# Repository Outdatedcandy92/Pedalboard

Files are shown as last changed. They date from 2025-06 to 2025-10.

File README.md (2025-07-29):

# DIY Guitar Pedals

>This project aims to create a DIY friendly and Mod-able version of  the iconic Boss DS-1 and Big Muff Pi.

Modern guitar pedals such as the DS-1 and Big Muff Pi are **super expensive**!! and the new pedals that are being produced all have SMD components which make it harder to mod and repair. I always wanted to get a DS-1 but its price tag really put me off, so I did a bit of research and found a really good circuit analysis of the DS-1 on [ElectroSmash's Website](https://www.electrosmash.com/boss-ds1-analysis) and decided to create my own [DS-1](https://github.com/Outdatedcandy92/DistortionPedal) and it was really rewarding project and the results were also very good. 
Since my DS-1 Version 1 had really good results, I decided to design an even upgraded version of it which fixes problems in version 1, In addition to that I also created a PCB for the Big Muff Pi.

https://github.com/user-attachments/assets/e87293e5-299d-45d1-807d-6a7f5c813e14

https://github.com/user-attachments/assets/bea94fd8-728a-4ede-ab68-e8244417e8f7

*DS-1 PCB*


*Big Muff PCB*


---

### DS-1









### Big Muff Pi








### 3PDT Breakout Board (Optional)





  ---
## BOM

More detailed BOM with parts lists is under the `src` folder 

### DS-1 Components
| **Reference** | **Value / Part Number** |
| --- | --- |
| C1, C3 | 47n |
| C2, C8, C9 | 0.47µF |
| C4 | 250pF |
| C5 | 68n |
| C7 | 100pF |
| C10 | 0.01µF |
| C11 | 0.022µF |
| C12 | 0.1µF |
| C13 | 0.047µF |
| C14 | 1µF |
| C15 | 47µF |
| C23 | 100µF |
| D1 | 1N4004 |
| D4, D5, D8 | D1N4148 |
| Q1, Q2, Q3 | 2SC2240 |
| R1, R22 | 1K |
| R2, R7 | 470K |
| R3, R8, R18, R21, R24, R25 | 10K |
| R4, R5, R10, R11, R23 | 100K |
| R9 | 22Ω |
| R13 | 4.7K |
| R14, R15 | 2.2K |
| R16, R17 | 6.8K |
| R19, R20 | 1M |
| R39 | 47K |
| U1 | NJM3404A (M5223AL, BA728N equiv.) |
| VR1, VR2 | 100KB |
| VR3 | 20KB |
| J1, J2 | 6.35mm Jacks |
| | |

### Big Muff Pi

| **Component Type** | **Value / Part Number** | **Designators** |
|---|---|---|
| NPN Transistors | BC239 or 2N5088, 2N5089, BC549C, SE4010, 2N5210 | Q1, Q2, Q3, Q4 |
| Silicon Diodes | 1N914 or 1N4148 | D1, D2, D3, D4 |
| Potentiometers (Lin) | 100K | Sustain, Tone, Volume |
| Resistors | 10K | R13, R19, R18, R11, R12 |
| Resistors | 100K | R20, R16, R3 |
| Resistors | 470K | R9, R17, R15 |
| Resistors | 39K | R2, R8 |
| Resistors | 150 | R21, R10 |
| Resistors | 15K | R6 |
| Resistor | 47K | R14 |
| Resistor | 100 | R22 |
| Resistor | 3.3K | R4 |
| Resistor | 1K | R23 |
| Resistor | 22K | R5 |
| Capacitors | 1µF | C1, C4, C6, C7 |
| Capacitors | 100nF | C5, C13, C3, C2 |
| Capacitors | 470pF | C10, C11, C12 |
| Capacitor | 4nF | C9 |
| Capacitor | 10nF | C8 |

#### Credits

[ElectroSmash Boss DS-1 Analysis](https://www.electrosmash.com/boss-ds1-analysis)
[ElectroSmash Big Muff Pi Analysis](https://www.electrosmash.com/big-muff-pi-analysis)

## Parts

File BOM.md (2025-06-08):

| **Component Type** | **Value / Part Number** | **Quantity** | Link | Price |
| --- | --- | --- | --- | --- |
| **Transistor** | 2SC2240 | 3 | [100pcs 2SC2240](https://www.aliexpress.com/item/1005009095677131.html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) | $3.33 |
| | BC239 or equiv. (2N5088, etc.) | 4 | [50pcs BC239B](https://www.aliexpress.com/item/1005005902190106.html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) | $3.02 |
| **Diode** | 1N4004 | 1 | [50pcs 1N4004](https://www.aliexpress.com/item/1005008196083877.html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) | $1.96 |
| | 1N4148 / 1N914 | 7 | [100pcs 1N4148](https://www.aliexpress.com/item/4000142272546.html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) | $2.81 |
| **IC** | NJM3404A / M5223AL / BA728N <br>*Note: these chips are hard to find so I'm using a NJM4558L* | 1 | [10pcs NJM4558L](https://www.aliexpress.com/item/33046960877.html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) | $3.03 |
| **Potentiometer** | 100KB | 5 | [10pcs WH148](https://www.aliexpress.com/item/1005004591016818.html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) | $3.82 |
| | 20KB | 1 | [10pcs WH148](https://www.aliexpress.com/item/1005004591016818.html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) | $3.83 |
| **Connector** | 6.35mm Jack | 4 | [10pcs Mono TS Jack](https://www.aliexpress.com/item/1005006997184592.html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) | $5.99 |
| | Screw In Terminal (2 Pin) | 4 | [10pcs 2 Pin Terminal](https://www.aliexpress.com/item/1005001677869988.html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) | $2.73 |
| | Screw In Terminal (3 Pin) | 6 | [10pcs 3 Pin Terminal](https://www.aliexpress.com/item/1005001677869988.html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) | $3.04 |
| **Resistor** | 22Ω | 1 | [600pcs Resistor Set](https://www.aliexpress.com/item/1005005855324735.html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) | $4.79 |
| | 100Ω | 1 | | |
| | 150Ω | 2 | | |
| | 1K | 3 | | |
| | 2.2K | 2 | | |
| | 3.3K | 1 | | |
| | 4.7K | 1 | | |
| | 6.8K | 2 | | |
| | 10K | 9 | | |
| | 15K | 2 | | |
| | 22K | 1 | | |
| | 39K | 2 | | |
| | 47K | 2 | | |
| | 100K | 5 | | |
| | 470K | 5 | | |
| | 1M | 2 | | |
| **Capacitor** | 100pF | 1 | [300pcs Ceramic Capacitor Kit](https://www.aliexpress.com/item/1005002990099454.html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) | $4.20 |
| | 250pF | 1 | | |
| | 470pF | 3 | | |
| | 4nF | 1 | | |
| | 10nF | 1 | | |
| | 22nF | 1 | | |
| | 47nF | 2 | | |
| | 68nF | 1 | | |
| | 100nF | 4 | | |
| | 0.1µF | 1 | | |
| | 0.47µF | 3 | [Aluminum Electrolytic Capacitor Kit](https://www.aliexpress.com/item/1005002983034947.html?spm=a2g0o.order_list.order_list_main.23.1f211802riqBFL) | $4.79 |
| | 1µF | 5 | | |
| | 47µF | 1 | | |
| | 100µF | 1 | | |
| **Enclosure & Misc** | 125B Aluminium Enclosure | 2 | [3pcs 125B Enclosure](https://www.aliexpress.com/item/1005006576995606.html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) | $32.99 |
| | 3PDT Footswitch | 2 | [3pcs 3PDT Switch](https://www.aliexpress.com/item/32814406770.html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) | $9.80 |
| | Kapton Tape | 1 | [40mm Kapton Tape](https://www.aliexpress.com/item/1005007518587827.html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) | $7.49 |
| | Wire | - | [22AWG Wire Set](https://www.aliexpress.com/item/1005008935365802.html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) | $13.05 |
| | 9V Battery Clip | 2 | [5pcs Battery Clip](https://www.aliexpress.com/item/1005006208179111.html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) | $1.99 |
| **Decoration** *(Optional)* | Spray Paint + Primer | 2 colors | [Rust-Oluem painters touch](https://www.homedepot.ca/product/rust-oleum-painter-s-touch-2x-ultra-cover-multi-purpose-primer-white-340-g-aerosol-spray-paint/1000666144) | $27.94 |
| | Paint Markers | 1 | [8pcs Metal Marker](https://www.aliexpress.com/item/1005007488212515.html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) | $5.19 |
| **PCB** (from JLCPCB) | Big Muff | 1 | | $6.97 |
| | DS-1 | 1 | | $6.97 |
| | 3PDT Breakout (optional) | 1 | | $4.37 |
| | Shipping | | | $2.05 |
| | | | | |
| **Subtotal** | | | | $156.35 |
| **Grand Total (13% Taxes)** | | | | $177 CAD or $130 USD |

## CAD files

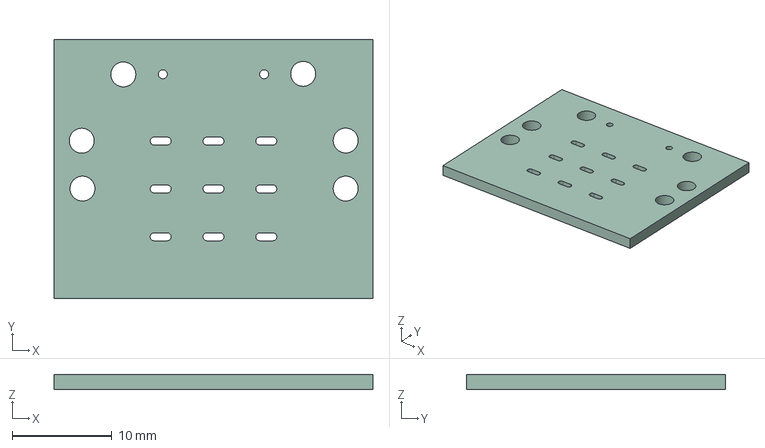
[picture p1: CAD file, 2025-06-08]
src/3PDT/CAD/ProPrj_Test_2025-06-08.step
32.0 x 26.0 x 1.51 mm

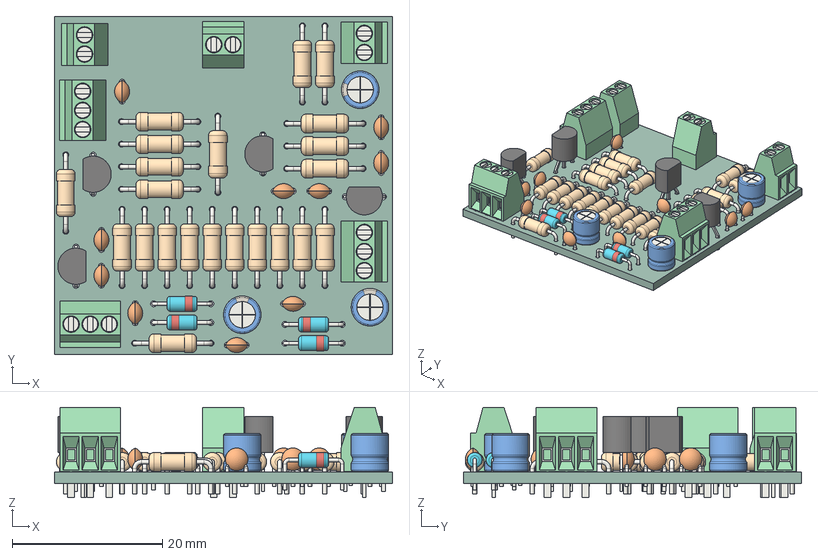
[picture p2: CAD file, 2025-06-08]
src/Big Muff Pi/CAD/Big_Muff.step
45.0 x 45.0 x 12.0 mm
R_Axial_DIN0207_L6.3mm_D2.5mm_P10.16mm_Horizontal x 22
D_DO-35_SOD27_P7.62mm_Horizontal x 4
CP_Radial_D5.0mm_P2.50mm x 3
TerminalBlock_Phoenix_MPT-0,5-2-2.54_1x02_P2.54mm_Horizontal x 3
C_Disc_D3.0mm_W2.0mm_P2.50mm x 10
TerminalBlock_Phoenix_MPT-0,5-3-2.54_1x03_P2.54mm_Horizontal x 3
TO-92_Inline_Wide x 4
Big_Muff_PCB

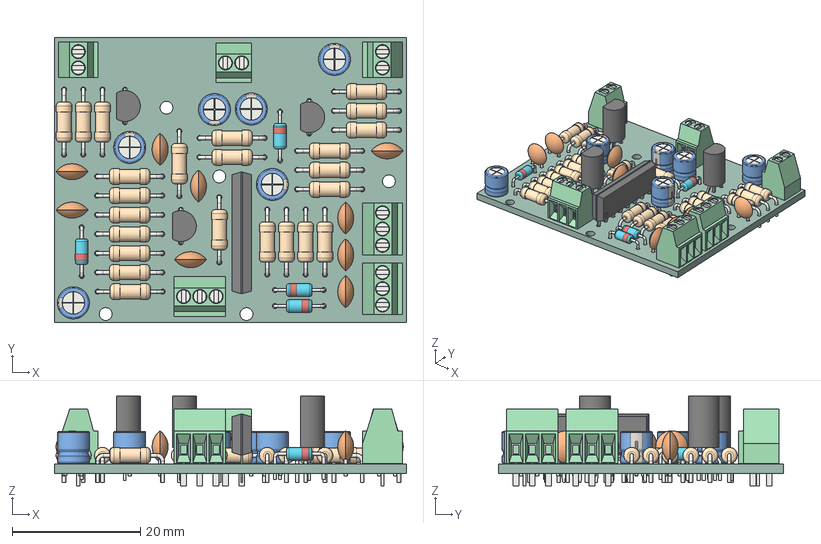
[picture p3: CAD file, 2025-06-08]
src/DS-1 V2/CAD/Distortion-v2.step
55.0 x 44.6 x 14.0 mm
TerminalBlock_Phoenix_MPT-0,5-2-2.54_1x02_P2.54mm_Horizontal x 3
R_Axial_DIN0207_L6.3mm_D2.5mm_P10.16mm_Horizontal x 24
D_DO-35_SOD27_P7.62mm_Horizontal x 4
C_Disc_D5.0mm_W2.5mm_P2.50mm x 9
CP_Radial_D5.0mm_P2.50mm x 6
TO-92L_Inline_Wide x 3
TerminalBlock_Phoenix_MPT-0,5-3-2.54_1x03_P2.54mm_Horizontal x 3
SIP-8_19x3mm_P2.54mm
Distortion-v2_PCB

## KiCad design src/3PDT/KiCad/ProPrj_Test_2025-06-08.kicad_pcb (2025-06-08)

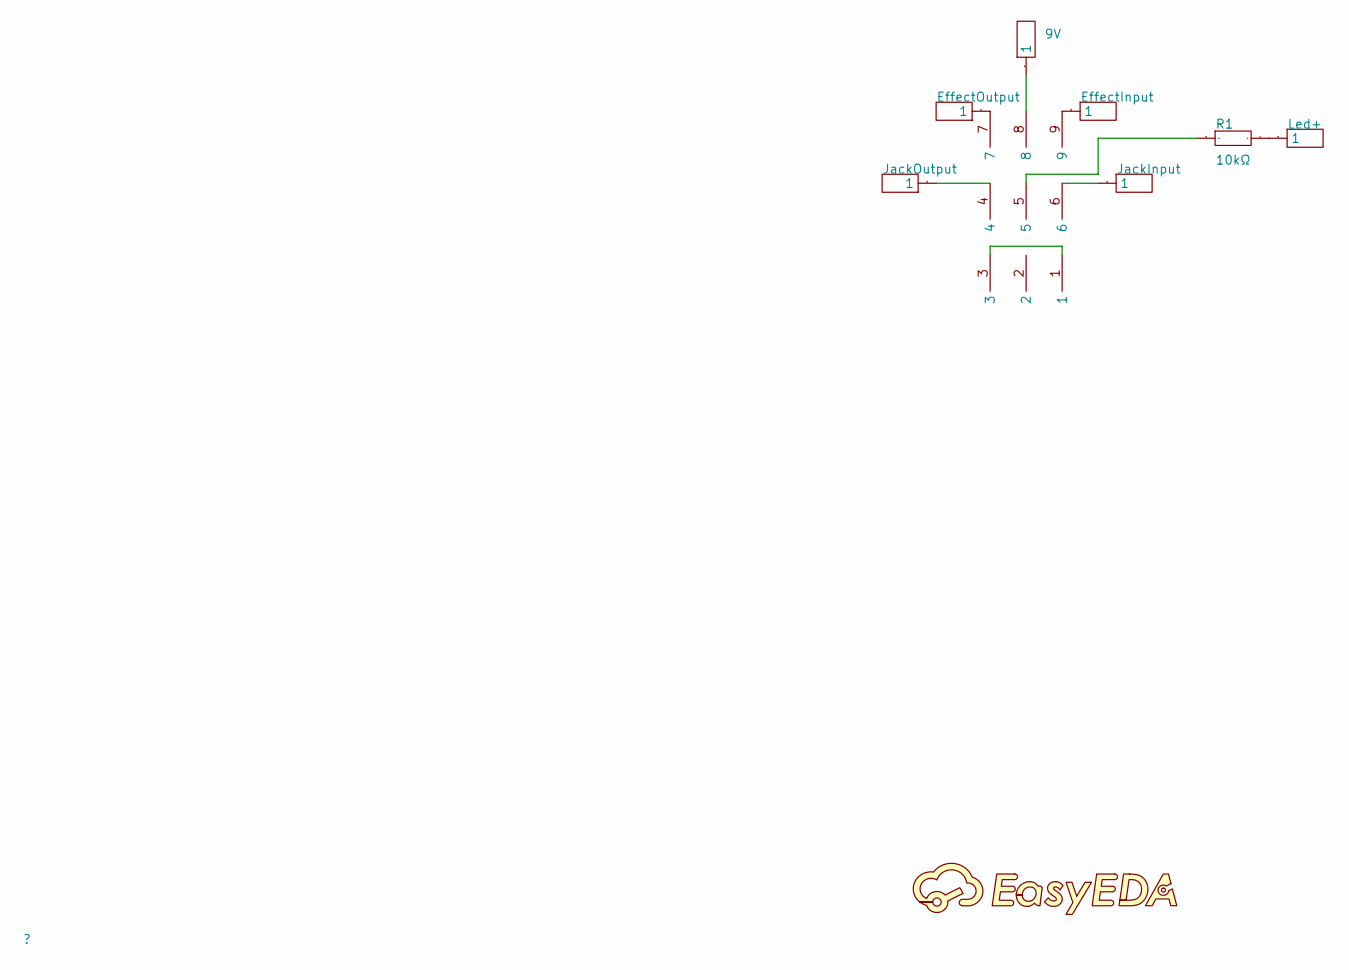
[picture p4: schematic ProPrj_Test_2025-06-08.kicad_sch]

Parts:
9V: HDR-TH_1P-V-M_XKB_X4611WV-01I-C28D40
EffectInput: HDR-TH_1P-V-M_XKB_X4611WV-01I-C28D40
EffectOutput: HDR-TH_1P-V-M_XKB_X4611WV-01I-C28D40
JackInput: HDR-TH_1P-V-M_XKB_X4611WV-01I-C28D40
JackOutput: HDR-TH_1P-V-M_XKB_X4611WV-01I-C28D40
Led+: HDR-TH_1P-V-M_XKB_X4611WV-01I-C28D40
R1: 10kΩ; R_AXIAL-0.4
U4: 3dpt

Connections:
$1N369: U4.1, U4.3
$1N418: JackOutput.1, U4.4
$1N421: JackInput.1, U4.6
$1N548: EffectInput.1, U4.9
$1N590: EffectOutput.1, U4.7
$1N612: 9V.1, U4.8
$1N706: Led+.1, R1.2
$1N710: R1.1, U4.5

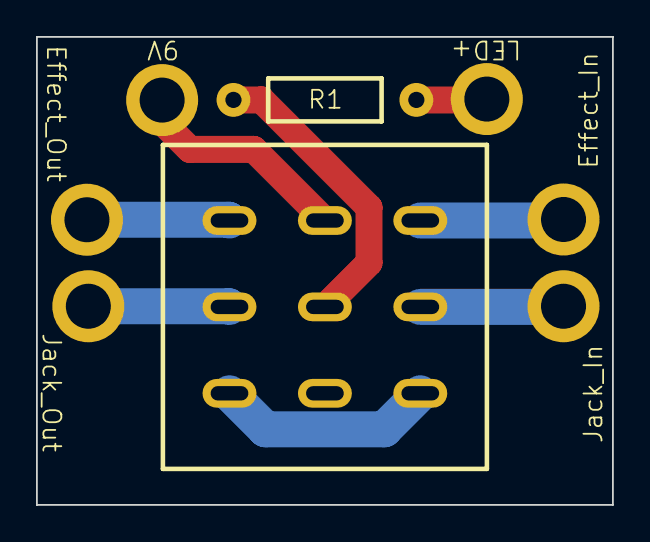
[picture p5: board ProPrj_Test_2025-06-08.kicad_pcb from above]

Board: 2 copper layers, 32.0 x 26.0 mm, 8 parts (0 on the bottom side), 8 nets.

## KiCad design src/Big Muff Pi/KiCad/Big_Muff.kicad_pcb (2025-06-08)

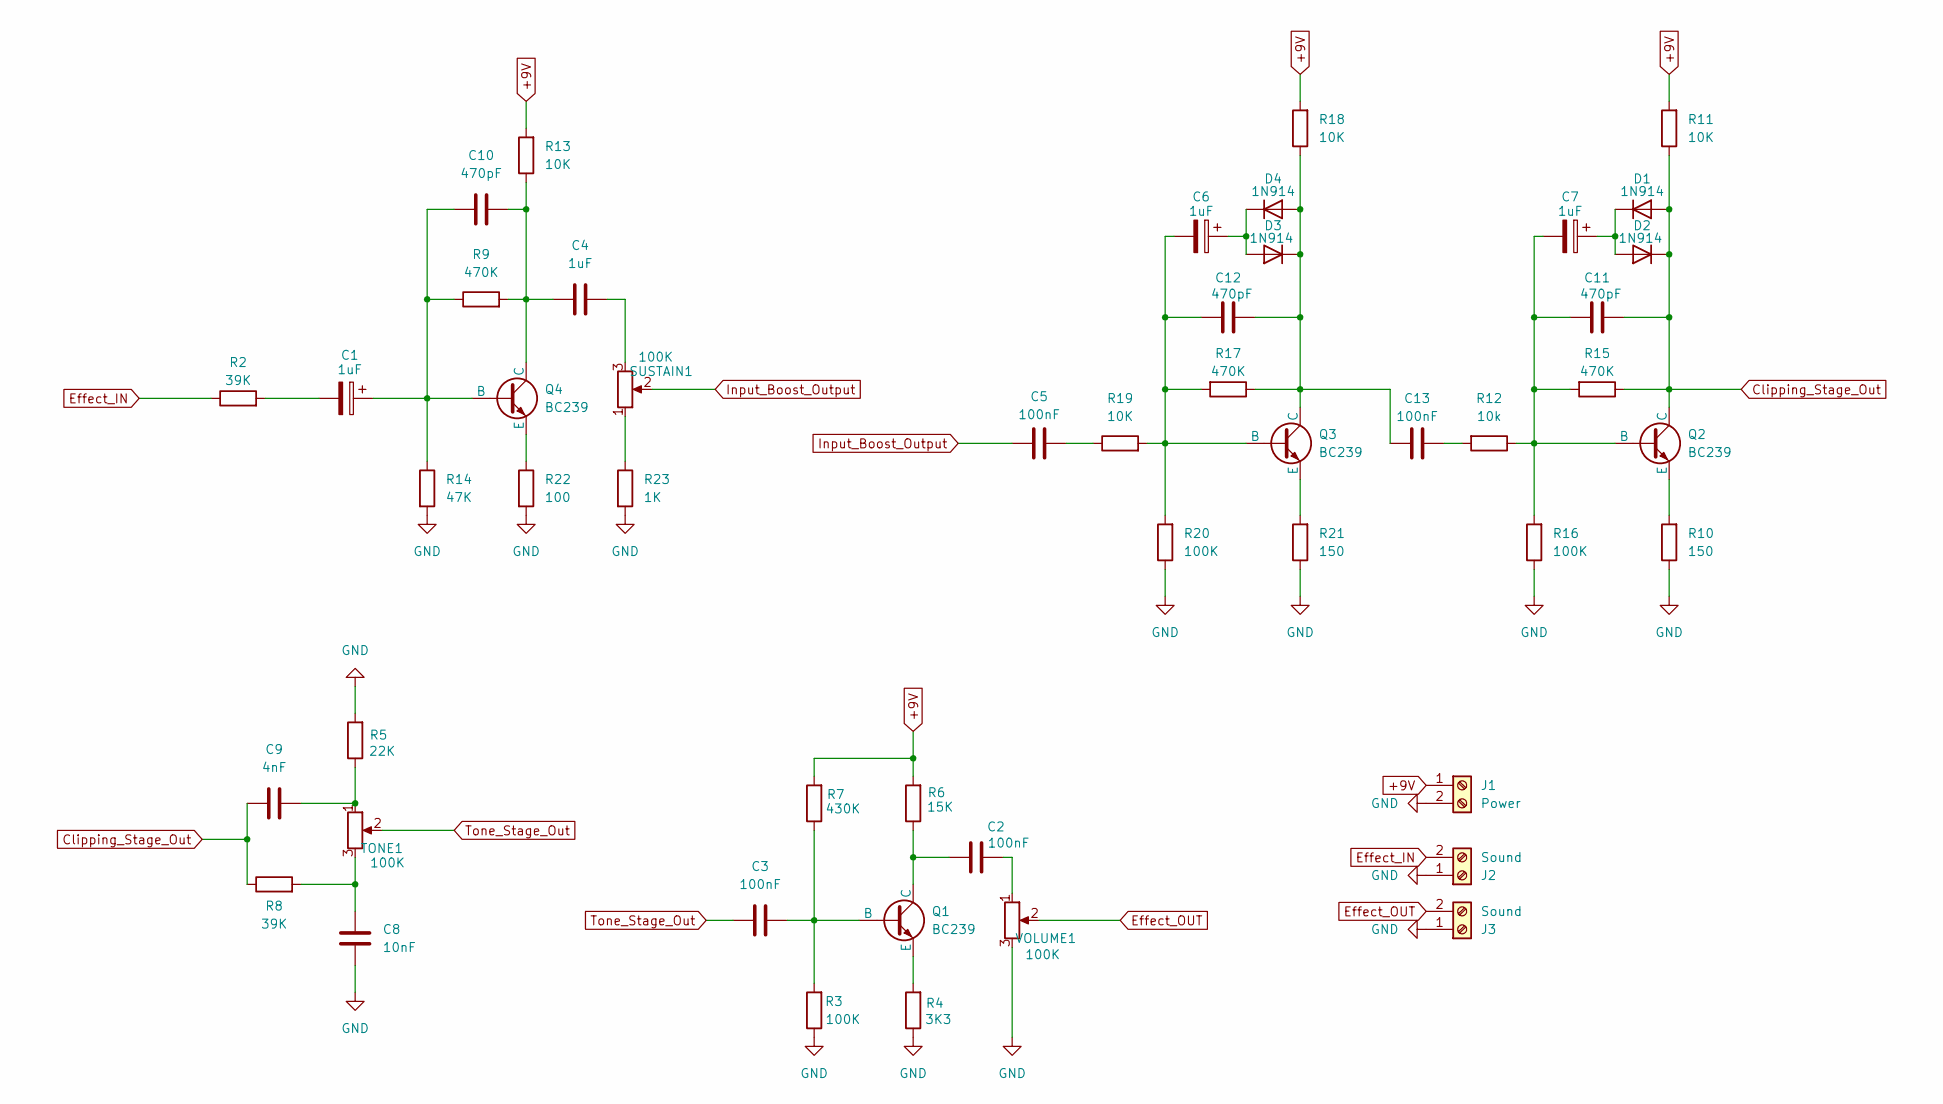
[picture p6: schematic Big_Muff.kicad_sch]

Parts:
C1, C6, C7: 1uF; CP_Radial_D5.0mm_P2.50mm
C2, C3, C5, C13: 100nF; C_Disc_D3.0mm_W2.0mm_P2.50mm
C4: 1uF; C_Disc_D3.0mm_W2.0mm_P2.50mm
C8: 10nF; C_Disc_D3.0mm_W2.0mm_P2.50mm
C9: 4nF; C_Disc_D3.0mm_W2.0mm_P2.50mm
C10, C11, C12: 470pF; C_Disc_D3.0mm_W2.0mm_P2.50mm
D1, D2, D3, D4: 1N914; D_DO-35_SOD27_P7.62mm_Horizontal
J1: Power; TerminalBlock_Phoenix_MPT-0,5-2-2.54_1x02_P2.54mm_Horizontal
J2, J3: Sound; TerminalBlock_Phoenix_MPT-0,5-2-2.54_1x02_P2.54mm_Horizontal
Q1, Q2, Q3, Q4: BC239; TO-92_Inline_Wide
R2, R8: 39K; R_Axial_DIN0207_L6.3mm_D2.5mm_P10.16mm_Horizontal
R3, R16, R20: 100K; R_Axial_DIN0207_L6.3mm_D2.5mm_P10.16mm_Horizontal
R4: 3K3; R_Axial_DIN0207_L6.3mm_D2.5mm_P10.16mm_Horizontal
R5: 22K; R_Axial_DIN0207_L6.3mm_D2.5mm_P10.16mm_Horizontal
R6: 15K; R_Axial_DIN0207_L6.3mm_D2.5mm_P10.16mm_Horizontal
R7: 430K; R_Axial_DIN0207_L6.3mm_D2.5mm_P10.16mm_Horizontal
R9, R15, R17: 470K; R_Axial_DIN0207_L6.3mm_D2.5mm_P10.16mm_Horizontal
R10, R21: 150; R_Axial_DIN0207_L6.3mm_D2.5mm_P10.16mm_Horizontal
R11, R13, R18, R19: 10K; R_Axial_DIN0207_L6.3mm_D2.5mm_P10.16mm_Horizontal
R12: 10k; R_Axial_DIN0207_L6.3mm_D2.5mm_P10.16mm_Horizontal
R14: 47K; R_Axial_DIN0207_L6.3mm_D2.5mm_P10.16mm_Horizontal
R22: 100; R_Axial_DIN0207_L6.3mm_D2.5mm_P10.16mm_Horizontal
R23: 1K; R_Axial_DIN0207_L6.3mm_D2.5mm_P10.16mm_Horizontal
SUSTAIN1: 100K; TerminalBlock_Phoenix_MPT-0,5-3-2.54_1x03_P2.54mm_Horizontal
TONE1: 100K; TerminalBlock_Phoenix_MPT-0,5-3-2.54_1x03_P2.54mm_Horizontal
VOLUME1: 100K; TerminalBlock_Phoenix_MPT-0,5-3-2.54_1x03_P2.54mm_Horizontal

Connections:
+9V: J1.1, R6.2, R7.2, R11.2, R13.2, R18.2
Clipping_Stage_Out: C9.1, C11.2, D1.2 (A), D2.1 (K), Q2.1 (C), R8.1, R11.1, R15.1
Effect_IN: J2.2, R2.1
Effect_OUT: J3.2, VOLUME1.2; also elsewhere on the board
GND: C8.1, J1.2, J2.1, J3.1, R3.1, R4.1, R5.2, R10.1, R14.2, R16.1, R20.1, R21.1, R22.2, R23.2, VOLUME1.3; also elsewhere on the board
Input_Boost_Output: C5.1, SUSTAIN1.2; also elsewhere on the board
unnamed: C1.2, R2.2
unnamed 7: C2.2, VOLUME1.1; also elsewhere on the board
unnamed 8: C4.2, SUSTAIN1.3; also elsewhere on the board
unnamed: C5.2, R19.1
unnamed 10: C8.2, R8.2, TONE1.3; also elsewhere on the board
unnamed 11: C9.2, R5.1, TONE1.1; also elsewhere on the board
unnamed: C13.2, R12.2
unnamed: C7.1, D1.1 (K), D2.2 (A)
unnamed: C6.1, D3.2 (A), D4.1 (K)
unnamed: C12.2, C13.1, D3.1 (K), D4.2 (A), Q3.1 (C), R17.1, R18.1
unnamed: C3.2, Q1.2 (B), R3.2, R7.1
unnamed: C2.1, Q1.1 (C), R6.1
unnamed: Q1.3 (E), R4.2
unnamed: C7.2, C11.1, Q2.2 (B), R12.1, R15.2, R16.2
unnamed: Q2.3 (E), R10.2
unnamed: C6.2, C12.1, Q3.2 (B), R17.2, R19.2, R20.2
unnamed: Q3.3 (E), R21.2
unnamed: C1.1, C10.1, Q4.2 (B), R9.1, R14.1
unnamed: C4.1, C10.2, Q4.1 (C), R9.2, R13.1
unnamed: Q4.3 (E), R22.1
unnamed 26: R23.1, SUSTAIN1.1; also elsewhere on the board
Tone_Stage_Out: C3.1, TONE1.2; also elsewhere on the board

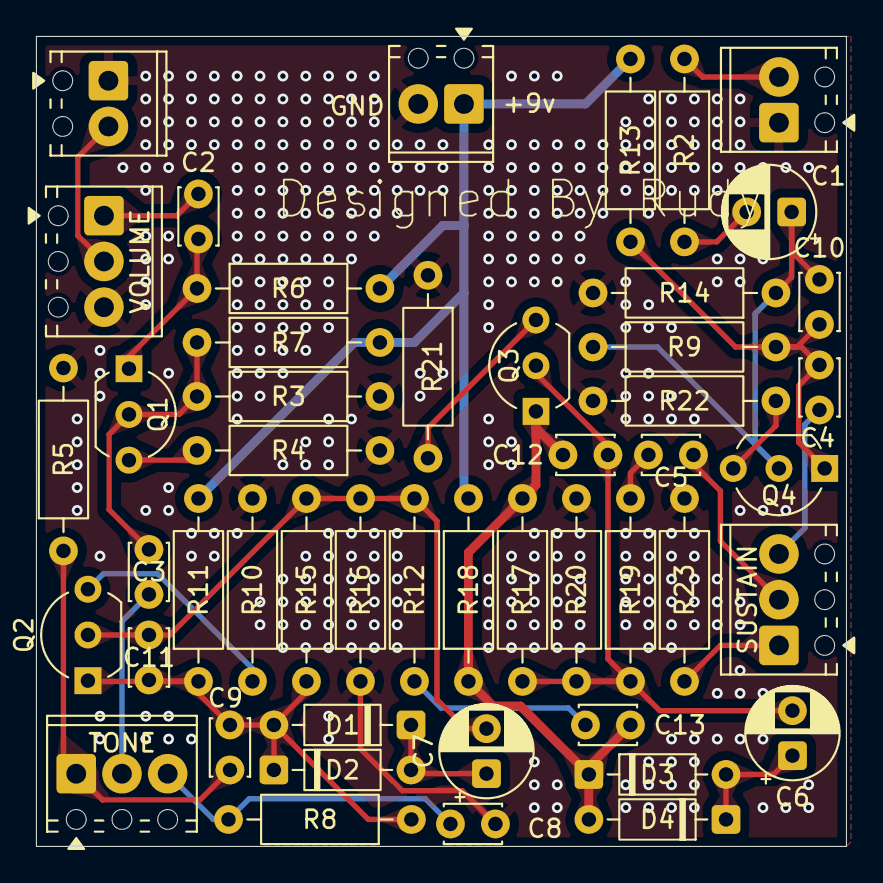
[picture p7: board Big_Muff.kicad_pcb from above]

Board: 2 copper layers, 45.0 x 45.0 mm, 49 parts (0 on the bottom side), 28 nets.

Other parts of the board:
SUSTAIN: 100K; TerminalBlock_Phoenix_MPT-0,5-3-2.54_1x03_P2.54mm_Horizontal
TONE: 100K; TerminalBlock_Phoenix_MPT-0,5-3-2.54_1x03_P2.54mm_Horizontal
VOLUME: 100K; TerminalBlock_Phoenix_MPT-0,5-3-2.54_1x03_P2.54mm_Horizontal

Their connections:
Effect_OUT: VOLUME.2; also elsewhere on the board
GND: VOLUME.3; also elsewhere on the board
Input_Boost_Output: SUSTAIN.2; also elsewhere on the board
unnamed 7: VOLUME.1; also elsewhere on the board
unnamed 8: SUSTAIN.3; also elsewhere on the board
unnamed 10: TONE.3; also elsewhere on the board
unnamed 11: TONE.1; also elsewhere on the board
unnamed 26: SUSTAIN.1; also elsewhere on the board
Tone_Stage_Out: TONE.2; also elsewhere on the board

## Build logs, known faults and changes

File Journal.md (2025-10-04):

## What am I making?
I'm making cheap DIY analog guitar effect pedals for Distortion and Fuzz. To ensure a high quality pedal I will be using reverse engineered schematic of the iconic Boss DS-1 and the Big Muff Pi. Careful planning will be done to ensure that these DIY pedals perform equally as well only for a fraction of the price, while still keeping in mind the Mod-ability and ease of repair.
## Time Spent Overall: 53 Hours

### My Goals For This Project-
- [ ] Only THT Components
- [ ] Easy to modify
- [ ] Cheap components

# Day 1 (17th May) - Started DS-1 

Since I already made a DS-1 pedal before I had experience with designing pedals and I also knew about stuff I should avoid adding in my design.
Some of those problems were -
- Having thin holes for the potentiometers
- Placing the potentiometer holes in the middle instead of at the edges
- Using holes to solder wire instead of having screw in terminals

To start with the project I made the DS-1 v2 schematics in kicad, the schematics for version 2 were similar to version one because the schematics just work!

*DS-1 Schematics*


I started out with PCB layout after finishing It. I always like to first start of with a rough layout to see how I can arrange my components and look at how I can improve from their and then restart the PCB layout again. 
This is exactly what I did for this design and by the end of the day I ended up with a layout that I liked.

The next step was routing everything together. Because I already made something like this I had experience and knew what to avoid while tracing. 
I carefully routed all the audio signals first, keeping the traces short and smooth. After that I routed my power traces, this time I made sure that the power traces were far away from the audio signal and that they also cross the audio traces are a 90 degree angle to reduce EMI and noise from the power trace radiating into the audio traces. This was a lesson I learned from making version 1, my power traces were routed improperly which introduced a 60hz hum from the cheap power supply into the audio signal, It worked fine but there was just a buzz which was a bit annoying.

This was the final result PCB design:


## Time Spent: 5 Hours

I was pretty locked in today!

# Day 2 (19th May) - Big Muff Schematic

I started working on designing the big muff pi schematic today. 

The big muff pi is pretty easy to make compared to a DS-1, and I finished making its schematics in like 30 mins.

After that I started working on the PCB for it. I again followed the same method I listed above of creating a rough layout then going to a finalized one. And this was the end result of the PCB.

*Big Muff Pi Schematics*


*Big Muff PCB Layout*



## Time Spent: 3 Hours

# Day 3 (5th June) - Updated DS-1 PCB

tl;dr I was pretty ambitious when starting this project but I have now decided to split this into three different projects.

After pondering and doing some research I've decided to actually split this project. Right now Im making a lot of pedals and Initially I though all of them could be made using analog circuitry, but I was wrong, for a lot of these effects I listed initially (chorus, eq, loop, noise gate) having a digital pedal is the only viable option. And so I have decided I'm going to split this into three different projects- one of which is this project (Distortion, Fuzz , the second project would be making a digital pedal that's capable of the effects listed above and is expandable, lastly the third project would be create a pedalboard for these pedals and a dedicated low noise power supply. Creating a digital pedal is way more complicated that I initially expected it to be and that's why I'm gonna keep it as its own separate project. 

Now back to the actual project. Today I did some minor revisions over the DS-1 PCB layout, I added ground pours on both top and bottom layers and stitched them together with a lot of vias. This will help keep ground plane continuity throughout the board and reduce EMI which in turn will reduce any buzzing/hiss generated by a noisy power supply (hopefully).


I also realized just now that I placed in the screw in terminal footprints in the wrong orientation. 

I updated the footprints and fixed the problem.

*DS-1 PCB*



## Time Spent: 2 Hours

# Day 4 (6th June) - Big Muff PCB

Today I started working on routing the Big Muff Pi, It was a pretty long and boring process but here is the final result



I'm not super happy with the way it came out for a few reasons-
- The power traces are long and cross through a lot of audio signals, while the traces cant be made any shorter I could route them in a much more efficient way.
- Very dense layout led to a lot of audio traces to be routed from on the bottom layer, while this is not that big of a deal I would prefer if most of the audio traces were on the top layer and only power traces were on the bottom

I also started working on making a BOM for this project today, I spent a lot of time just surfing on aliexpress for cheap component kits which include everything I require for this project. This took a few hours because I had to cross check the component values from the aliexpress listings to the component values required. Overall I finished about 60% of the BOM today.

## Time Spent: 5 Hours 

# Day 5 (June 7th) - Redid Everything

I finished making the BOM today and the overall cost comes up to about $90 USD which is a bit expensive but not bad considering that this is the cost for two pedals which would be something $180 USD if buying the originals. Also with all the parts in the BOM you could make about at least 4 of these pedals, the only thing bringing up the cost in our DIY scenario is the 125B Aluminium Enclosure. I think spending money on a Aluminium enclosure is 100% worth it, I've tried using a plastic case for my DS-1 version 1 and wrapping it with aluminium foil but it just doesn't shield it from EMI properly and is a big hassle overall, Its much better to get a solid enclosure which can handle the stomping and shield the internal circuitry from EMI.

I also decided to reroute the whole Big Muff PCB again and here are the results-
*Front*


*Back*


*With Fill*


Even though the Big Muff's schematics were easier compared to DS-1, routing the Big Muff was way way harder. This was a very dense layout and very complicated to route but nevertheless I finished routing It.

---

Well on second though I decided to completely scrape my PCB design and start a new one from scratch. There were far too many problems with the routing on version 1 of the Big Muff, there were a lot of traces overlapping and long power traces parallel to audio traces.
I decided to increase the board size a bit and have two separate screw in terminals for the guitar input and output. This was the layout I finally decided on-



In my humble opinion I would like to say that I absolutely cooked while making this. Its just so beautiful and organized, and much much better than the previous layout.

*PCB Front*


*PCB Back*


*PCB*


*CAD Render*


--- 

I also create a basic CAD design for the case, I'm gonna be using a 125B Aluminium enclosure so there was not much to design, I just had to place the components to get a rough idea of where to drill the holes later on. Anyways here is the case -



I'm still unsure if I should add some spray paint in my BOM and make my pedal colorful instead of just a grey box.

---

I also decided I should try panelizing the PCBs and order both PCB as one board to save cost and get more boards, but in order to do that I had to reduce the size of the DS-1 PCB down a few mm. So I decided to start off fresh for the DS-1 PCB and this time set the board size to 45x45mm. I spent a few hours creating a new layout and ended up with this -



After about a hour or so of routing I ended up with this masterpiece-

*Front*


*Back*


*Render*


I also have like 22 DRC errors about edge clearance violations and courtyard overlaps but I'm gonna pretend like I didn't see that.

---

I panelized my design now I can now get 5 boards each for the price of 1. There probably wasn't a need to do this as ordering it separately would have only costed like 2 dollars more but I always wanted to learn how to panelize and this seemed like a great opportunity for it.





I can fit like 4 boards (2 of each design) into one panel but I think ill use the rest of the space for a 3PDT switch breakout board which I'll make tommorow.

Overall I would say today was my most productive day, I've been working on this project since morning and basically redid everything today.

## Time Spent: 10 Hours

# Day 6 (7th June)

I decided to make a breakout board for the 3PDT footswitch as soldering wires directly to it gets messy after a while. I made the design in Easyeda because they had a footprint for the switch, then I imported it into KiCad.

*PCB In EasyEDA*


*PCB imported into KiCad*


*Breakout Board Render*


---
My project was basically finished at this point. I added the breakout board into the panelized design and this was the result-

*PCB Panel*


*Panel Render*


---

**Aw hell nah!** The panel actually ended up costing more, I guess jlcpcb doesn't like it when you cram 3 different designs onto a single board. 

*Panelized Design*


*Individual PCBs*


Well panelizing it was a waste of time but atleast I learned something new.

---

I spent about an hour or so updating my BOM and formatting everything in the project repo, the overall cost comes up to about $130 USD which is a bit more that I anticipated but hey atleast the pedal will look good this time.

## Time Spent: 3 Hours

# 23 June - Painting the enclosures

Most of my parts have arrived by now. I'm now waiting for my pinecil to arrive so I can solder the board (I broke my aliexpress iron).

I 3D printed a stencil as a guide for drilling holes in my enclosure (People usually print it out on paper and then use it but I don't have a regular printer so I decided to 3D print it), I drilled out 2 aluminium enclosures using my cordless Ikea drill and a step drill bit. This took a long time and created a lot of aluminum shavings in my room. 

I sanded down both the enclosures with a 150 grit sandpaper (that was the highest grid I had, ideally you should go with 600 or higher) and then spray painted them outside.

The black enclosure sort of got a wierd hammertone finish almost by complete accident and I like it a lot so I'm gonna keep it.
II tried cutting a tape stencil on the orange one but realized that the knife had actually cut the paint and left marks, so I decided to start over again. I resanded the enclosure, had to remove all the paint from it which was a long and tedious process, and then spray painted it again. This time I decided to leave it as is and not add a stencil.

*Sanded orange enclosure*


*final enclosures*

## Time Spent: 7 Hours

# June 24 - More painting

Today I sanded the bottom of the enclosures and painted them too.



## Time Spent: 1 Hours

# June 26 - DS-1

My pinecil arrived today and I soldered my DS-1 board. It DID NOT work.
I'll have to most likely start over again and this time check the outputs at every stage




no worky :c

## Time Spent: 2 Hours

# June 28 - Big Muff Assembly

I soldered up my big muff board today, I made sure to check its output at every stage before moving on, the final assembled board was outputting something on my oscilloscope which was a nice sign but it was really late at night so I did not actually test it.

*testing its output on a scope*



*Final Assembled PCB*


## Time Spent: 4 Hours

# June 29 - Big Muff Testing

I tested out my big muff today and it WORKS! the sound is a bit choppy kind of, and cuts off if i close the enclosure, it sound a lot different than my old DS-1, and it kind of sounds muffed which makes sense cause its the big muff (duh).

Also I did a 1000iq move, so I actually messed up my 3PDT breakout board by making the pads too small to fit, well, I'm very smart so I ended up surface mounting the THT switch on it and well it works! 

*surface mounted tht*


*video demo*
https://github.com/user-attachments/assets/e87293e5-299d-45d1-807d-6a7f5c813e14
## Time Spent: 2 Hours

# July 3 - DS-1 Troubleshooting

I tried soldering another DS-1 board and this time checking its output on every stage, and it turn out I used the wrong symbol/footprint for my transistor. 
It turns out not all transistors have the standard cbe layout some have a messed up bce layout which I had no idea even existed.

*breadboarding the transistor and finding out it has a different pinout*


## TIme Spent: 1 Hour

# July 5 - DS-1 Jank

So luckily I had a transistor kit and one of those transistors had a bce layout.
I accidentally soldered in my op amp the wrong way on the pcb and desoldering it was impossible so I had to start again.

*PCB*


After finally assembling everything properly this time I went on to test the pedal, to be honest it sounded pretty awful, it was very quiet and buzzy because of the swapped out transistors. At this point i just decided to order a new pcb with fixed footprint for the transistor.

## Time Spent: 5 Hours

# 19 July - DS-1 Works!

I got my new PCB and soldering everything together, I ran out of screw in terminals so I just soldered the wires directly on the PCB.

The DS-1 works now, but it kinda pops a lot which I'm assuming is probably because of a loose wire connection to the potentiometer.



*video demo*
https://github.com/user-attachments/assets/bea94fd8-728a-4ede-ab68-e8244417e8f7
## Time Spent: 3 Hours
